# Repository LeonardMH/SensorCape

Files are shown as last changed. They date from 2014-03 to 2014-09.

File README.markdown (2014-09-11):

# SensorCape

This is the project repository for the SensorCape for BeagleBone Black. The SensorCape is a highly capable add-on for the BeagleBone that adds the following functionality:

+ 3-axis gyroscope
+ 3-axis accelerometer
+ 3-axis magnetometer (compass)
+ Ambient light sensor
+ Ambient temperature sensor
+ Non-contact temperature sensor
+ Humidity sensor
+ Pressure sensor (Detects altitude changes)
+ 38 kHz IR sensor (Interfaces with common consumer electronics)
+ 4 push-buttons
+ 4 user-configurable LED's 

The repository hosts both the hardware files and the software library that is used to interact with the onboard sensors. Visit the [project page](http://michaelhleonard.com/projects/SensorCape) for further information and documentation.

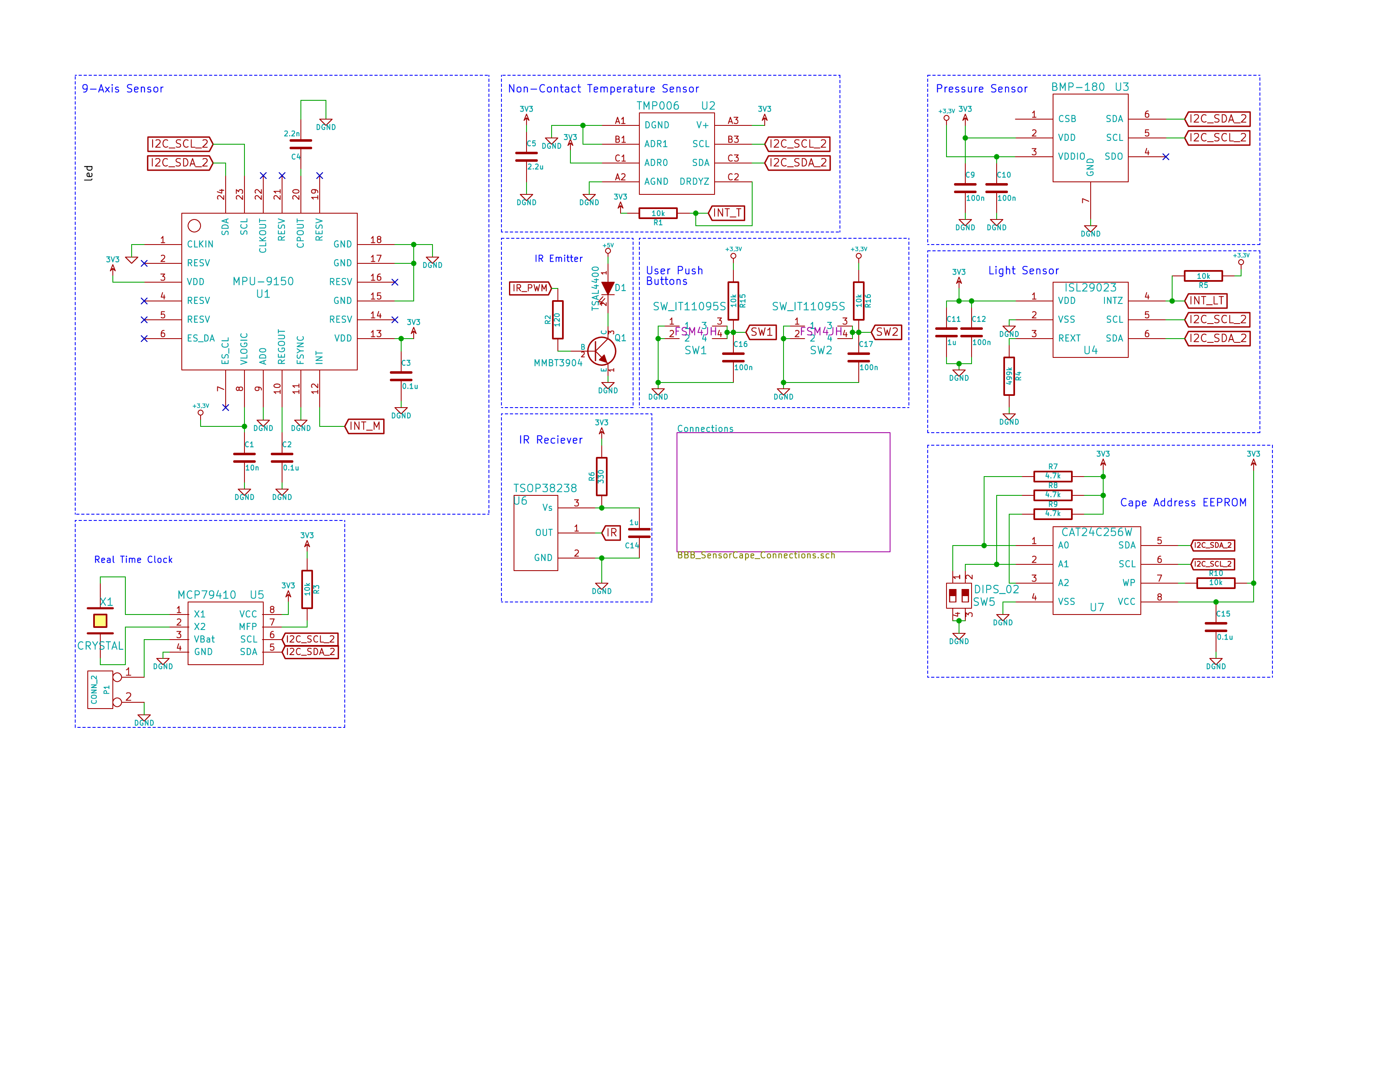
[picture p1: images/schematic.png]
Schematic snapshot of most recent SensorCape


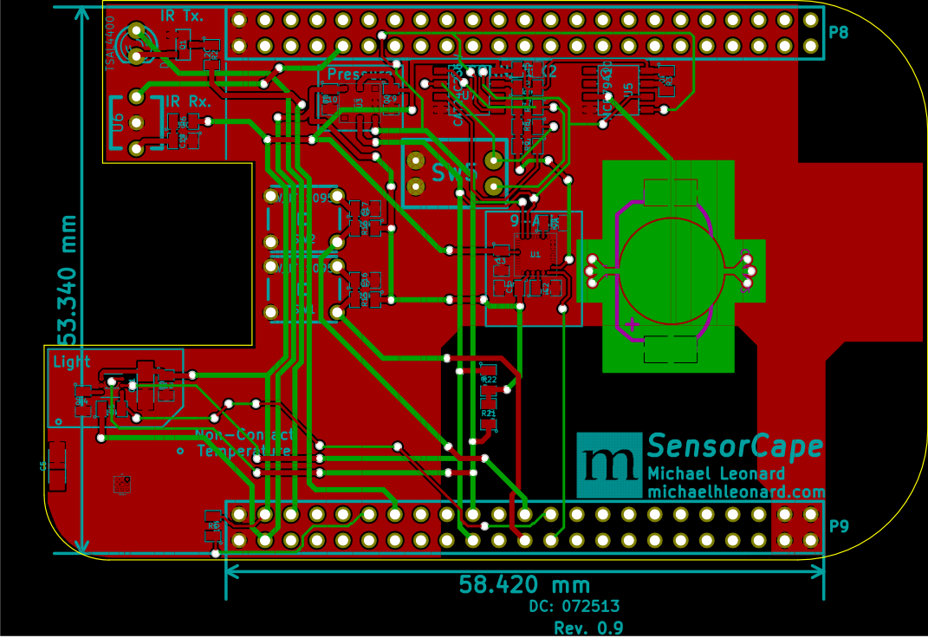
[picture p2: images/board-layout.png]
Board layout snapshot of most recent SensorCape


## Checking out a specific folder

Since 2012 it has been possible to check out a specific folder in a git repository. This means that if you would like to develop or use the software but don't need the hardware files you don't have to clone them to your local computer. See [this stack overflow question](http://stackoverflow.com/questions/600079/is-there-any-way-to-clone-a-git-repositorys-sub-directory-only) for more info or [read this tutorial](http://jasonkarns.com/blog/subdirectory-checkouts-with-git-sparse-checkout/). You may also want to check out [the official documentation](http://schacon.github.io/git/git-read-tree.html#_sparse_checkout).

I would recommend just cloning the entire repository.

# Licenses

Hardware and software are released under the following licenses.

## Hardware

The SensorCape hardware is released under the open source ["SolderPad Hardware License"](http://solderpad.org/licenses/SHL-0.51/). The license disclaimer is below. This is an open source and fairly non-restrictive license.

Copyright SensorCape, Michael Leonard, Copyright and related rights are licensed under the Solderpad Hardware License, Version 0.51 (the “License”); you may not use this file except in compliance with the License. You may obtain a copy of the License at http://solderpad.org/licenses/SHL-0.51. Unless required by applicable law or agreed to in writing, software, hardware and materials distributed under this License is distributed on an “AS IS” BASIS, WITHOUT WARRANTIES OR CONDITIONS OF ANY KIND, either express or implied. See the License for the specific language governing permissions and limitations under the License.

## Software

The software library for the SensorCape (if it is ever finished) is released under the open source ["GNU Lesser General Public License v2.1"](http://www.gnu.org/licenses/lgpl-2.1.html). The license disclaimer is below. This is an open source and fairly non-restrictive license.

SensorCape for BeagleBone Black hardware interface library.
Copyright (C) 2014  Michael Leonard

This library is free software; you can redistribute it and/or
modify it under the terms of the GNU Lesser General Public
License as published by the Free Software Foundation; either
version 2.1 of the License, or any later version.

This library is distributed in the hope that it will be useful,
but WITHOUT ANY WARRANTY; without even the implied warranty of
MERCHANTABILITY or FITNESS FOR A PARTICULAR PURPOSE.  See the GNU
Lesser General Public License for more details.

You should have received a copy of the GNU Lesser General Public
License along with this library; if not, write to the Free Software
Foundation, Inc., 51 Franklin Street, Fifth Floor, Boston, MA  02110-1301  USA

You can contact me on GitHub as user [LeonardMH](http://github.com/LeonardMH).

# Contributors

Michael Leonard - [My Website](http://michaelhleonard.com/)

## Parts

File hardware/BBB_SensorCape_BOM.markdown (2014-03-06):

Designator | Package | Qty. | Description | Manufacturer | Manufacturer Ref. | Supplier | Supplier Ref. | CPU ($) | Total | Comments
--- | --- | --- | --- | --- | --- | --- | --- | --- | --- | --- 
C1 | 0805 | 1 | 10nF |  Ceramic |  X7R |  10% |  4V | Murata | GRM216R71E103KA01D | Mouser | 81-GRM216R71E103KA01,$0.28,$0.28,
C2 |  C3 | 0805 | 2 | 0.1uF |  Ceramic |  X7R |  10% |  4V | Murata | GRM219R71C104KA01D | Mouser,81-GRM40X104K16D,$0.13,$0.26,
C4 | 0805 | 1 | 2.2n |  Ceramic X7R |  10% |  50V | Murata | GRM216R71H222KA01D | Mouser | 81-GRM40X222K50D | $0.27,$0.27,
C5 | Tantalum A | 1 | 2.2uF |  >= 10V | Vishay/Sprague | 293D225X9010A2TE3 | Mouser | 74-293D225X9010A2TE3 | $0.60 | $0.60 | 
C9 |  C10 |  C12 |  C16 | C17 |  C18 |  C19 | 0805 | 7 | 100nF |  Ceramic |  X5R, 10V,Murata,GRM219R71C104KA01D,Mouser,81-GRM40X104K16D,$0.13,$0.91,
C11 | Tantalum A | 1 | 1uF |  >= 10V | Vishay/Sprague | 293D105X9025A2TE3 | Mouser | 74-293D105X9025A2TE3 | $0.17 | $0.17 | 
C14 | 0805 | 1 | 1uF |  Ceramic |  X5R |  10V | Vishay/Vitramon | VJ0805Y105KXQTW1BC | Mouser | 77-VJ0805Y105KXQTBC | $0.06,$0.06,
C15 | 0805 | 1 | 0.1uF |  Ceramic |  X7R |  16V | Murata | GRM219R71C104KA01D | Mouser | 81-GRM40X104K16D | $0.13,$0.13,
R1 |  R5 |  R10 | R15 | R16 |  R17 |  R18 | 0805 | 7 | 10k |  1/10W | Vishay/Dale,CRCW080510K0FKEA,Mouser,71-CRCW0805-10K-E3,$0.08,$0.56,
R6 | 0805 | 1 | 330 |  1/10W  | Vishay/Dale | CRCW0805330RFKEA | Mouser | 71-CRCW0805-330-E3 | $0.08 | $0.08 | 
R7 |  R8 |  R9 |  R21 |  R22 | 0805 | 5 | 4.7k |  1/10W | Vishay/Dale | CRCW08054K70FKEB | Mouser,71-CRCW08054K70FKEB,$0.08,$0.40,
R4 | 0805 | 1 | 499k |  1/10W | Vishay/Dale | CRCW0805499KFKEA | Mouser | 71-CRCW0805-499K-E3 | $0.08 | $0.08 | 
U1 | LGA_24_4x4 | 1 | 9-Axis Sensor | InvenSense | MPU-9150 | DigiKey | 1428-1009-1-ND | $12.70 | $12.70 | 
U2 | BGA_DS_9 | 1 | Non-contact temperature sensor | Texas Instruments | TMP006AIYZFR | DigiKey | 296-28819-1-ND | $3.89 | $3.89 | Be sure to get the 3.3 V version
U3 | BMP180 | 1 | Pressure sensor | Bosch | BMP180 | DigiKey | 828-1027-1-ND | $4.80 | $4.80 | 
U4 | ODFN_6 | 1 | Digital light sensor | Intersil | ISL29023 | DigiKey | ISL29023IROZ-T7CT-ND | $3.00 | $3.00 | 
U6 | TSOP_3 | 1 | 38 kHz IR sensor | Vishay | TSOP38238 | DigiKey | 751-1227-ND | $0.91 | $0.91 | 
U7 | so-8 | 1 | Cape address EEPROM | ON Semiconductor | CAT24C256WI-G | DigiKey | CAT24C256WI-G-ND | $0.80 | $0.80 | 
SW1 |  SW2 |  SW3 |  SW4 | FSM4JH | 4 | Through hole tactile switch | TE Connectivity | FSM4JH | DigiKey | 450-1650-ND | $0.10,$0.40,
SW5 | DIPS-DS02 | 1 | DIP Switch | E-Switch | KAS1102ET | DigiKey | EG4486-ND | $1.17 | $1.17 | 
P8 |  P9 | PIN_ARRAY_23X2 | 2 | 46 pin headers | Major League | SSHQ-123-D-08-GT-LF | Major League | SSHQ-123-D-08-GT-LF | $2.14 | $4.28 |

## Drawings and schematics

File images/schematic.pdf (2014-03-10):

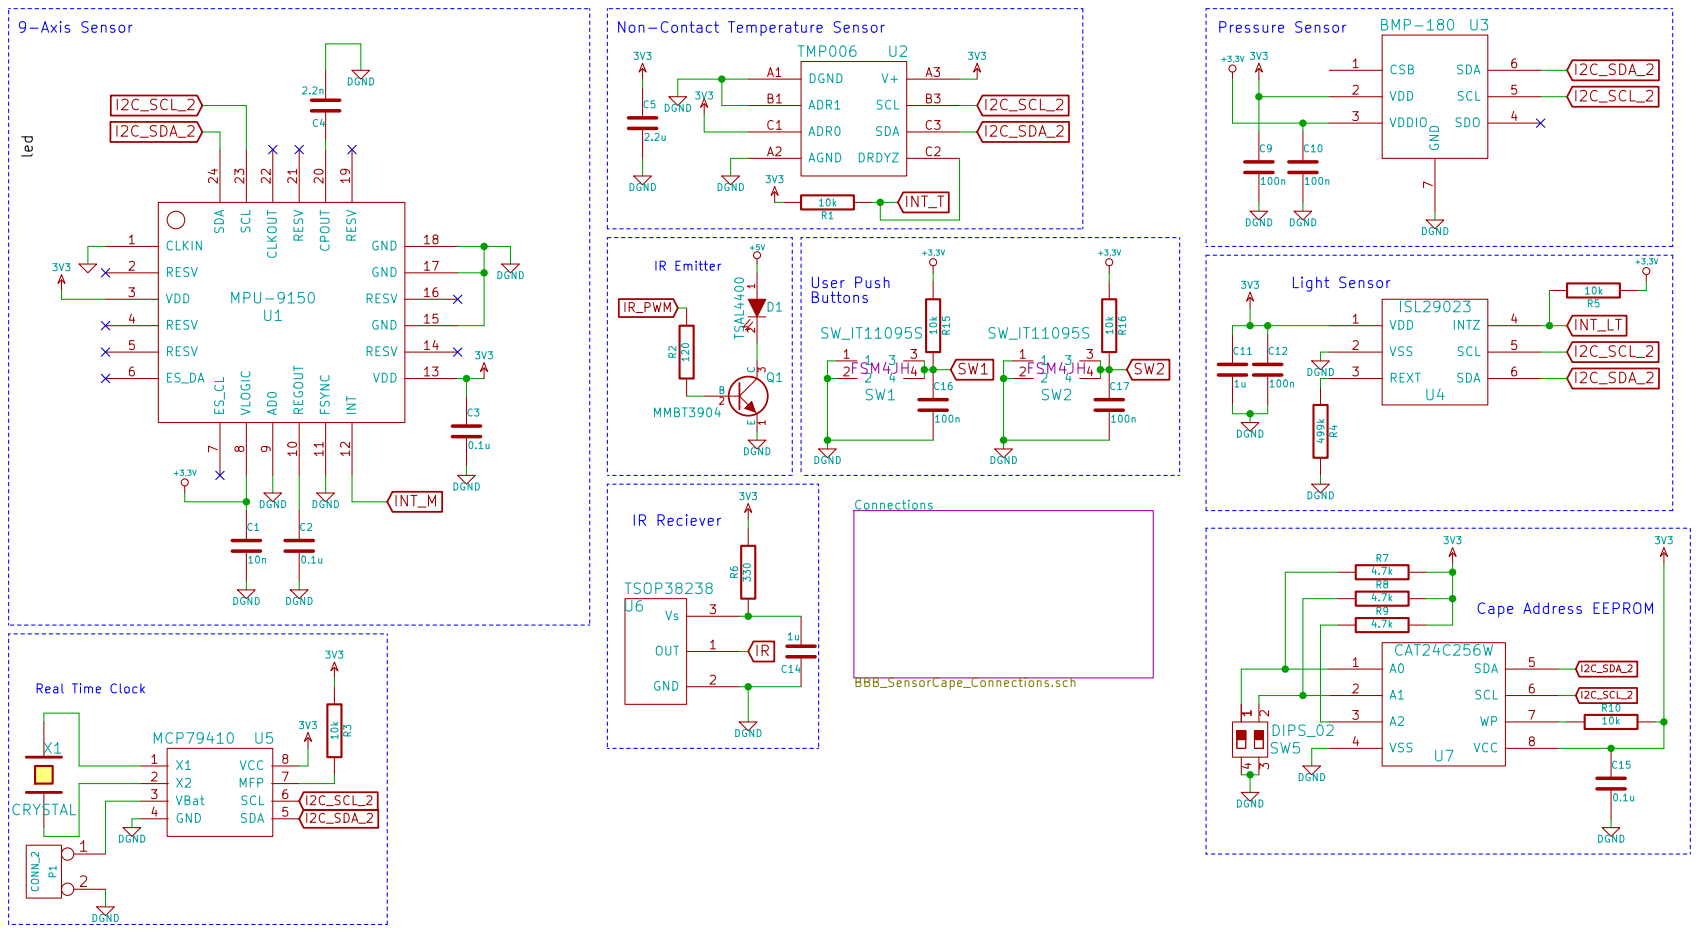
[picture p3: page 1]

led CLKIN 1 RESV 2 VDD 3 RESV 4 RESV 5 ES_DA 6 ES_CL

9 REGOUT 10 CPOUT 20 FSYNC 11 RESV 21 INT 12 CLKOUT 22 VDD 13 SCL 23 RESV 14 SDA 24 GND 15 RESV 16 GND 17 GND RESV 18 19 U1 MPU-9150

SW2 User Push ButtonsConnections BBB_SensorCape_Connections.sch

DGND X1 CRYSTAL Real Time Clock 1

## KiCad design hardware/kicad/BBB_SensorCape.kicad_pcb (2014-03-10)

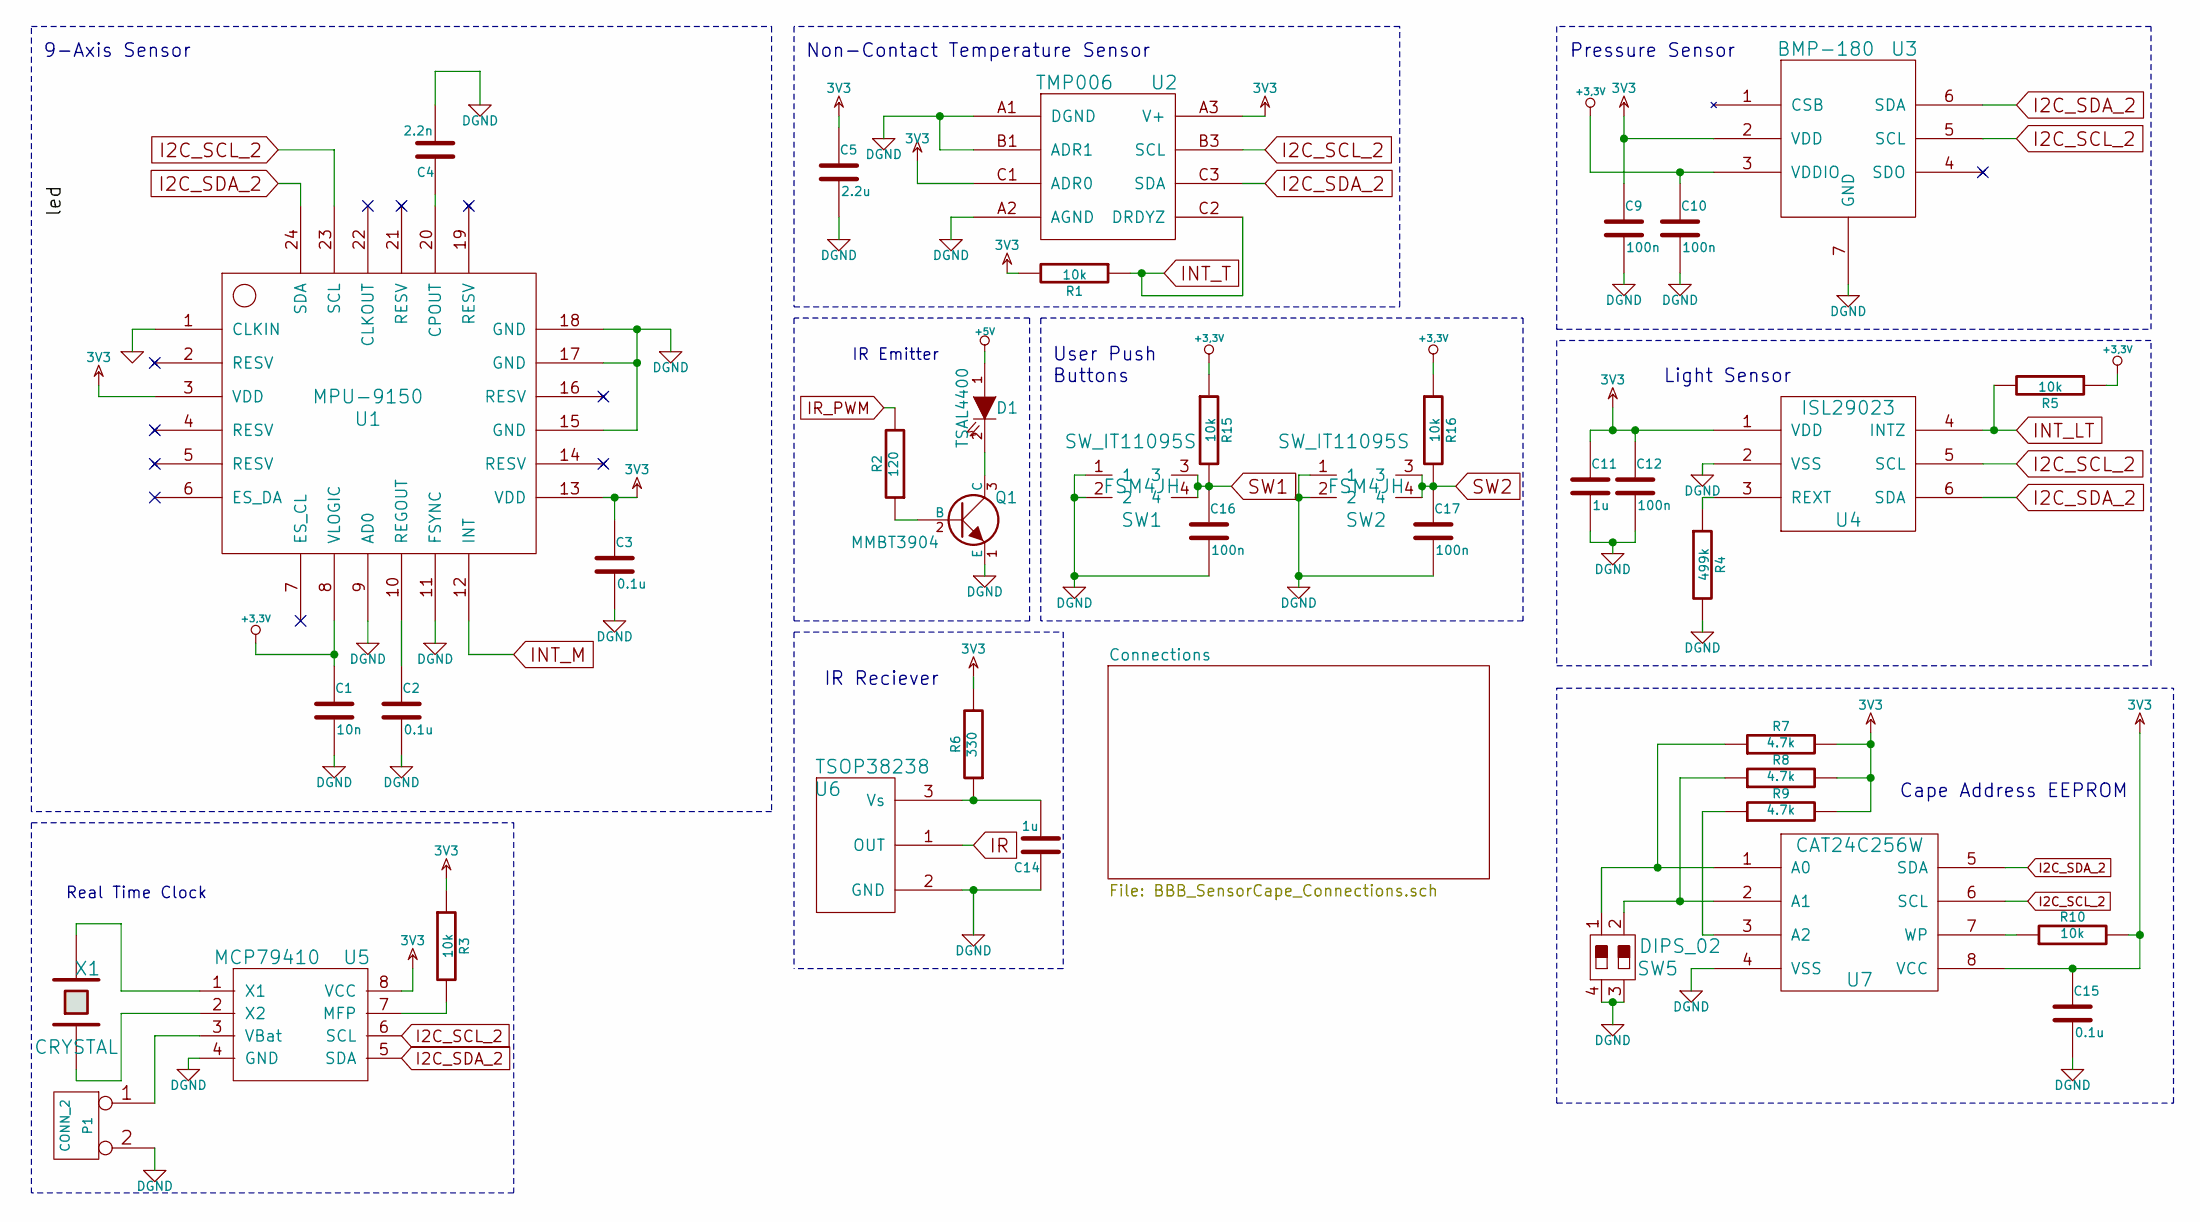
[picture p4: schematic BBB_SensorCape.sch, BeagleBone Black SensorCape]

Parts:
C1: 10n
C2, C3, C15: 0.1u
C4: 2.2n
C5: 2.2u
C9, C10, C12, C16, C17: 100n
C11, C14: 1u
D1: TSAL4400
P1: CONN_2
Q1: MMBT3904
R1, R3, R5, R10, R15, R16: 10k
R2: 120
R4: 499k
R6: 330
R7, R8, R9: 4.7k
SW1, SW2: SW_IT11095S; FSM4JH
SW5: DIPS_02
U1: MPU-9150
U2: TMP006
U3: BMP-180
U4: ISL29023
U5: MCP79410
U6: TSOP38238
U7: CAT24C256W
X1: CRYSTAL

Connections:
3V3: C3.1, C5.1, C9.1, C11.1, C12.1, C15.1, R1.2, R3.1, R6.2, R7.2, R8.2, R9.2, R10.2, U1.3 (VDD), U1.13 (VDD), U2.A3 (V+), U2.C1 (ADR0), U3.2 (VDD), U4.1 (VDD), U5.8 (VCC), U7.8 (VCC); also elsewhere on the board
+3.3V: C1.1, C10.1, R5.1, R15.1, R16.1, U1.8 (VLOGIC), U3.3 (VDDIO); also elsewhere on the board
+5V: D1.1 (A); also elsewhere on the board
DGND: C1.2, C2.2, C3.2, C4.2, C5.2, C9.2, C10.2, C11.2, C12.2, C14.1, C15.2, C16.2, C17.2, P1.2 (PM), Q1.1 (E), R4.2, SW1.1, SW1.2, SW2.1, SW2.2, SW5.3, SW5.4, U1.9 (AD0), U1.11 (FSYNC), U1.15 (GND), U1.17 (GND), U1.18 (GND), U2.A1 (DGND), U2.A2 (AGND), U2.B1 (ADR1), U3.7 (GND), U4.2 (VSS), U5.4 (GND), U6.2 (GND), U7.4 (VSS); also elsewhere on the board
I2C_SCL_2: U1.23 (SCL), U2.B3 (SCL), U3.5 (SCL), U4.5 (SCL), U5.6 (SCL), U7.6 (SCL); also elsewhere on the board
I2C_SDA_2: U1.24 (SDA), U2.C3 (SDA), U3.6 (SDA), U4.6 (SDA), U5.5 (SDA), U7.5 (SDA); also elsewhere on the board
INT_LT: R5.2, U4.4 (INTZ); also elsewhere on the board
INT_M: U1.12 (INT); also elsewhere on the board
INT_T: R1.1, U2.C2 (DRDYZ); also elsewhere on the board
IR: U6.1 (OUT); also elsewhere on the board
IR_PWM: R2.2; also elsewhere on the board
unnamed: R9.1, U7.3 (A2)
unnamed: Q1.2 (B), R2.1
unnamed: R10.1, U7.7 (WP)
unnamed: U5.1 (X1), X1.2
unnamed: U5.2 (X2), X1.1
unnamed: P1.1, U5.3 (VBat)
unnamed: D1.2 (K), Q1.3 (C)
unnamed: R3.2, U5.7 (MFP)
unnamed: R4.1, U4.3 (REXT)
unnamed: C4.1, U1.20 (CPOUT)
unnamed: C2.1, U1.10 (REGOUT)
unnamed: R8.1, SW5.2, U7.2 (A1)
unnamed: R7.1, SW5.1, U7.1 (A0)
unnamed: C14.2, R6.1, U6.3 (Vs)
SW1: C16.1, R15.2, SW1.3, SW1.4; also elsewhere on the board
SW2: C17.1, R16.2, SW2.3, SW2.4; also elsewhere on the board

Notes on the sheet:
9-Axis Sensor
Non-Contact Temperature Sensor
Pressure Sensor
Light Sensor
IR Reciever
Cape Address EEPROM
User Push Buttons
IR Emitter
Real Time Clock

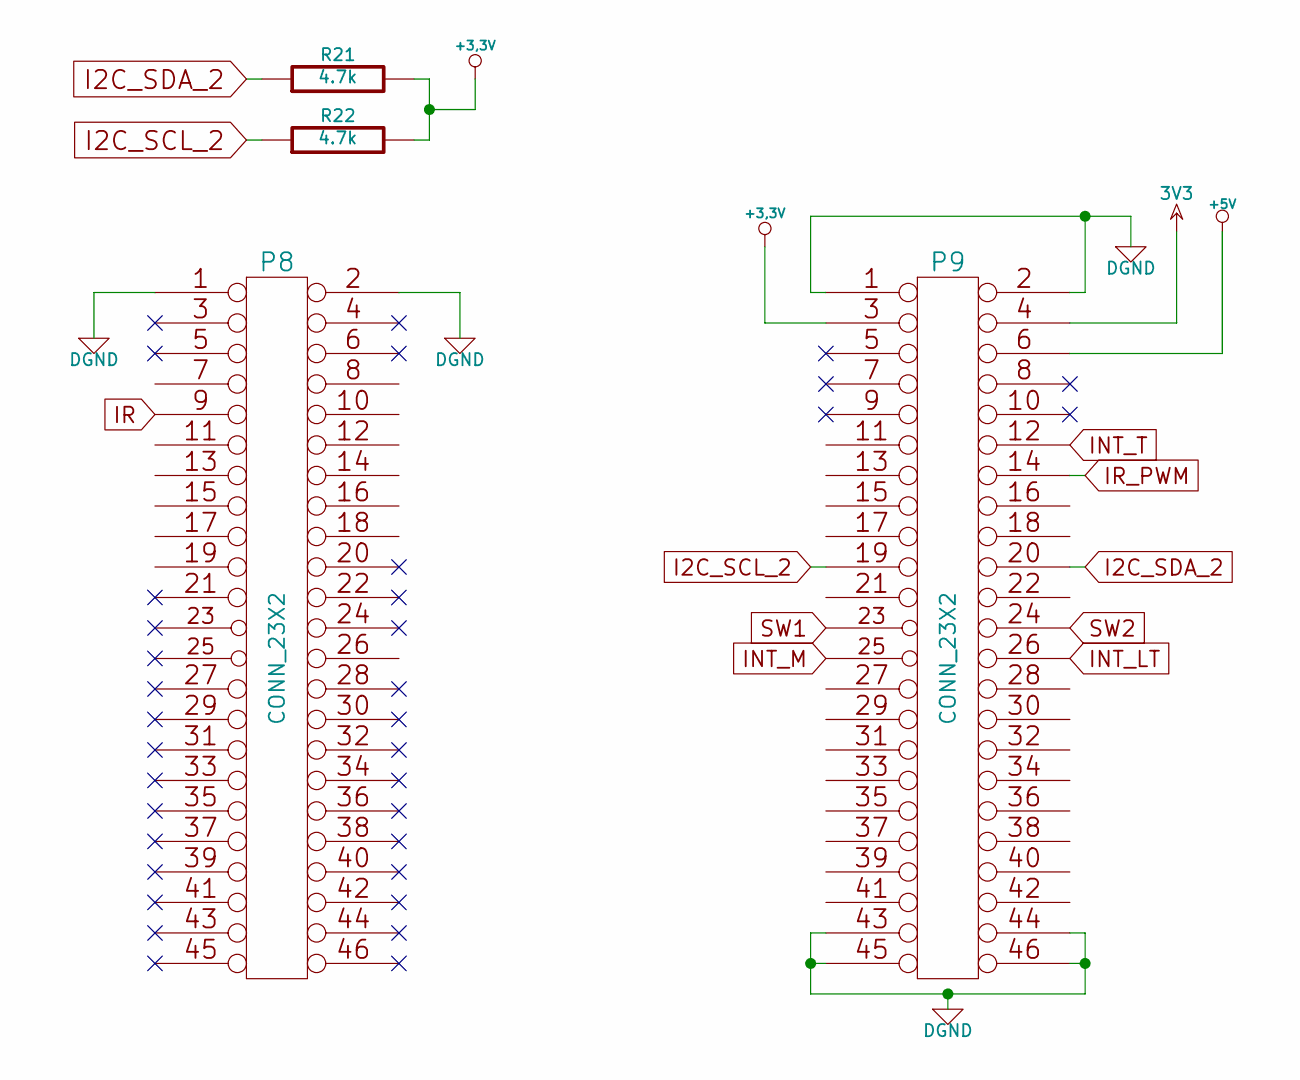
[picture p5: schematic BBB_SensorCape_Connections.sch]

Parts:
P8, P9: CONN_23X2
R21, R22: 4.7k

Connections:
3V3: P9.4; also elsewhere on the board
+3.3V: P9.3, R21.2, R22.2; also elsewhere on the board
+5V: P9.6; also elsewhere on the board
DGND: P8.1, P8.2, P9.1, P9.2, P9.43, P9.44, P9.45, P9.46; also elsewhere on the board
I2C_SCL_2: P9.19, R22.1; also elsewhere on the board
I2C_SDA_2: P9.20, R21.1; also elsewhere on the board
INT_LT: P9.26; also elsewhere on the board
INT_M: P9.25; also elsewhere on the board
INT_T: P9.12; also elsewhere on the board
IR: P8.9; also elsewhere on the board
IR_PWM: P9.14; also elsewhere on the board
SW1: P9.23; also elsewhere on the board
SW2: P9.24; also elsewhere on the board

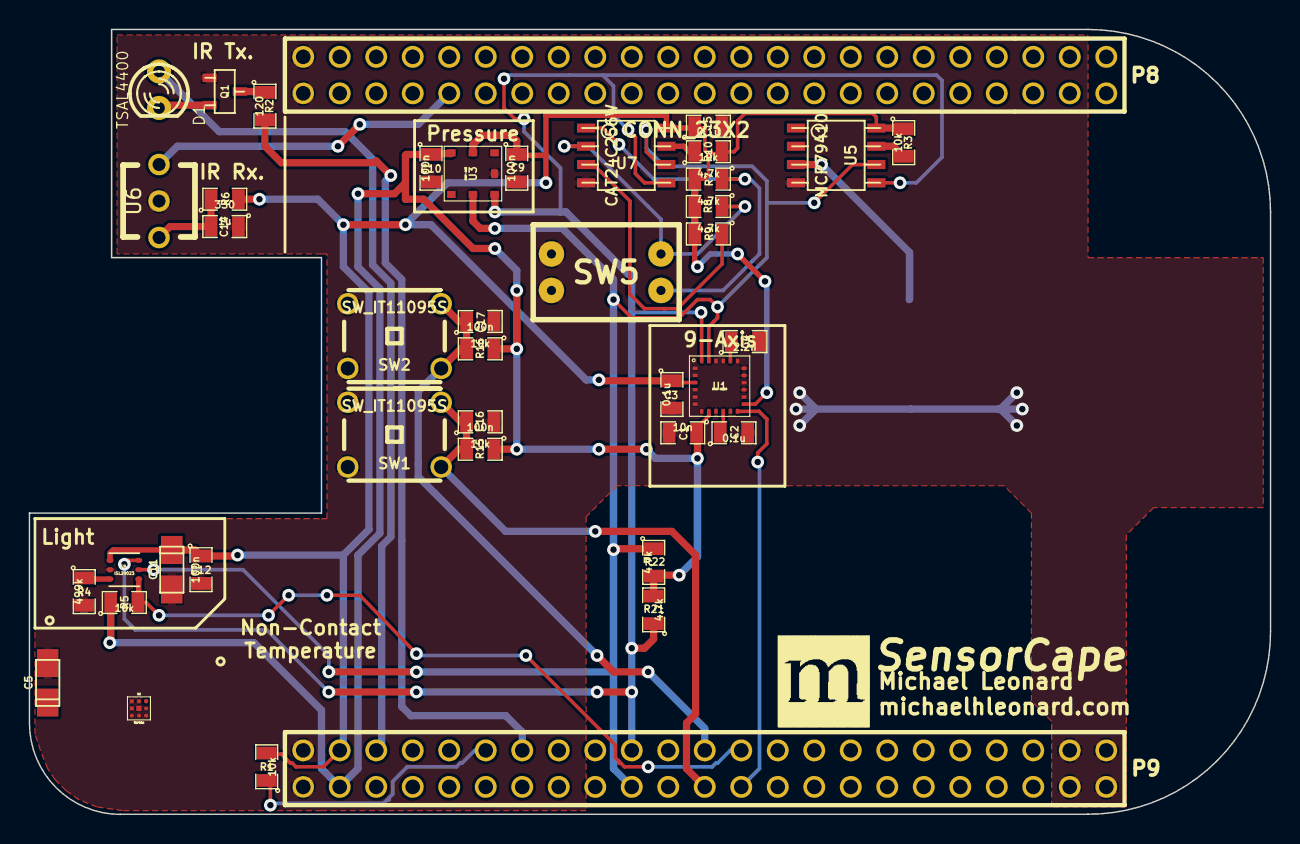
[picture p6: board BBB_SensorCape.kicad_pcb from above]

Board: 2 copper layers, 86.4 x 54.6 mm, 43 parts (1 on the bottom side), 25 nets.

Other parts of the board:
LOGO: LOGO

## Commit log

2013-07-02 Add some class functionality to SensorCape.h. Began work on motion.h
2013-07-03 Basic LED functionality implemented. Will add GPIO next.
2013-07-03 Added a neat LED test using the USR leds on the BBB.
2013-07-03 Minor updates to SensorCape and motion classes.
2013-07-03 Updated README.md
    Uses hyperlinks, placed the project page more prominently, added a short description of the SensorCape
2013-07-09 Removed threading from test.cpp
2013-07-09 Begin work on I2C class
2013-07-11 Add basic byte/word read and write functionality to i2c library
2013-07-11 Implemented the functions to read sensor data from MotionSensor, untested
2014-03-06 Renamed SensorCape_v0.2_clib to just clib, I will let git handle version changes
2014-03-06 Added hardware files to repository
    [BBB_SensorCape.kicad_pcb, BBB_SensorCape.sch, BBB_SensorCape_BOM.xlsx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]
2014-03-06 Added a raw BOM file
2014-03-10 Reworking directory structure, allow git to handle versions
    [BBB_SensorCape.kicad_pcb, BBB_SensorCape.sch, BBB_SensorCape_BOM.xlsx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]
2014-03-10 Added files for hardware version 0.9
    [BBB_SensorCape.kicad_pcb, BBB_SensorCape.sch, BBB_SensorCape_Connections.sch]
2014-03-10 Added files for hardware version 1.0
    [BBB_SensorCape.kicad_pcb]
2014-03-10 Added board and schematic images for v1.0
2014-03-10 Added some automatically generated backup files
    [BBB_SensorCape.kicad_pcb, BBB_SensorCape.sch, BBB_SensorCape_Connections.sch]
2014-09-11 Update README to include open source licenses for hardware and software.
    Hardware: SolderPad Hardware License
    Software GNU Lesser General Public License v2.1
